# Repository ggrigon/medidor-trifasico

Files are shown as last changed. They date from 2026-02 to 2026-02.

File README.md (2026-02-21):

# Medidor de Tensão Trifásico - ESP32 + PZEM-004T

Medidor trifásico DIY para monitoramento de sistema 220/380V em tempo real. Lê tensão, corrente, potência, energia, frequência e fator de potência das 3 fases com interface web, display OLED, histórico em SD card e integração MQTT.

**Custo estimado:** ~R$ 350-430 (vs R$ 900+ de soluções comerciais como Shelly Pro 3EM)

**Landing page:** [ggrigon.github.io/medidor-trifasico](https://ggrigon.github.io/medidor-trifasico/)

## Funcionalidades

- **Leitura das 3 fases:** tensão, corrente, potência, energia, frequência, fator de potência
- **Display OLED:** 5 páginas auto-rotativas (overview + detalhe de cada fase + alarmes)
- **Dashboard Web:** interface responsiva com gráficos em tempo real via WebSocket
- **Histórico SD Card:** log CSV diário (~1.5 MB/dia), cartão de 32GB = ~58 anos
- **MQTT:** integração com Home Assistant, Grafana (via Telegraf + InfluxDB)
- **Alarmes:** sobretensão (>253V) e subtensão (<197V) com buzzer, LED e notificação web
- **OTA:** atualização de firmware via Wi-Fi

## Lista de Materiais

| # | Componente | Qtd | Função |
|---|---|---|---|
| 1 | ESP32 DevKit V1 (30 pinos, CP2102) | 1 | Microcontrolador principal - WiFi + Bluetooth |
| 2 | PZEM-004T v3.0 com TC split-core 100A | 3 | Medidor de energia por fase (Modbus RTU) |
| 3 | Display OLED SSD1306 128x64 I2C | 1 | Display local para leituras |
| 4 | Módulo SD Card SPI | 1 | Armazenamento de histórico CSV |
| 5 | Cartão microSD (4GB+ classe 10) | 1 | Mídia de armazenamento |
| 6 | Buzzer passivo 5V (BP18) | 1 | Alarme sonoro |
| 7 | Placa perfurada dupla face | 1 | Montagem dos componentes |
| 8 | Fios jumper Dupont (M-M, M-F) | ~40 | Conexões entre componentes |
| 9 | Resistor 4.7k 1/4W | 2 | Pull-up I2C (SDA/SCL) |
| 10 | Resistor 330R 1/4W | 1 | Limitador LED status |
| 11 | Capacitor eletrolítico 100uF 16V | 1 | Desacoplamento 5V |
| 12 | Capacitor cerâmico 100nF 50V | 1 | Filtro 3.3V |
| 13 | LED verde 3mm | 1 | Indicador de status |
| 14 | Borne KRE 2 vias | 1-6 | Conexões parafusadas |
| 15 | Barras de pinos macho/fêmea | 3 | Soquetes e conectores |
| 16 | Fonte 5V 1A (USB ou HLK-PM01) | 1 | Alimentação do ESP32 |

> **IMPORTANTE:** Os PZEMs devem ter CT tipo **split-core** (aberto, tipo grampo). NÃO comprar com CT fechado (closed loop). Ver detalhes completos em [`LISTA_MATERIAIS.md`](LISTA_MATERIAIS.md).

## Pinagem

```
ESP32 GPIO16 (RX2) ──bus──> 3x PZEM TX   (Modbus RTU, addr 0x01/0x02/0x03)
ESP32 GPIO17 (TX2) ──bus──> 3x PZEM RX
ESP32 GPIO21 (SDA) ──────> OLED SDA      (pull-up 4.7k para 3.3V)
ESP32 GPIO22 (SCL) ──────> OLED SCL      (pull-up 4.7k para 3.3V)
ESP32 GPIO23 (MOSI) ─────> SD MOSI
ESP32 GPIO19 (MISO) ─────> SD MISO
ESP32 GPIO18 (SCK) ──────> SD SCK
ESP32 GPIO5  (CS) ───────> SD CS
ESP32 GPIO4  ────────────> Buzzer passivo
ESP32 GPIO2  ── R 330R ──> LED verde
```

Ver esquemático completo em [`hardware/schematic.pdf`](hardware/schematic.pdf) ou [`hardware/schematic.txt`](hardware/schematic.txt).

## Estrutura do Projeto

```
medidor-trifasico/
├── platformio.ini              # Configuração PlatformIO
├── partitions.csv              # Tabela de partições customizada (1.87MB app + 2.06MB LittleFS)
├── LISTA_MATERIAIS.md          # Lista detalhada com preços e links de compra (BR)
├── STATUS.md                   # Andamento do projeto
├── src/
│   ├── main.cpp                # Setup/loop, orquestração cooperativa com millis()
│   ├── config.h                # Pinos, constantes, structs (PhaseData, MeterData)
│   ├── pzem_reader.h/.cpp      # Leitura dos 3 PZEMs via Modbus RTU
│   ├── display_manager.h/.cpp  # OLED SSD1306 (5 páginas rotativas)
│   ├── web_server.h/.cpp       # AsyncWebServer + WebSocket (tempo real)
│   ├── mqtt_client.h/.cpp      # Publicação MQTT (Home Assistant / Grafana)
│   ├── sd_logger.h/.cpp        # Log CSV no SD card (rotação diária)
│   ├── alarm_manager.h/.cpp    # Alarmes sub/sobretensão com buzzer
│   ├── wifi_manager.h/.cpp     # WiFi STA + fallback AP
│   ├── ntp_time.h/.cpp         # Sincronização NTP
│   └── ota_manager.h/.cpp      # Atualização OTA via Wi-Fi
├── data/                        # LittleFS -> dashboard web
│   ├── index.html
│   ├── style.css
│   ├── app.js
│   └── chart.min.js.gz
├── hardware/                    # Projeto PCB KiCad 7 (90x80mm, 2 camadas)
│   ├── medidor-trifasico.kicad_pro
│   ├── medidor-trifasico.kicad_sch
│   ├── medidor-trifasico.kicad_pcb
│   ├── schematic.pdf
│   └── schematic.txt
└── tools/
    └── set_pzem_addresses.cpp   # Utilitário config endereços PZEM
```

## Instalação

### Pré-requisitos
- [PlatformIO CLI](https://platformio.org/install/cli) ou PlatformIO IDE (VS Code)
- Cabo USB-C para o ESP32

### 1. Configurar endereços dos PZEMs

Cada PZEM precisa de um endereço Modbus único. De fábrica, todos vêm com 0xF8. Configure um por vez:

```bash
# Conecte apenas 1 PZEM ao ESP32
# Edite tools/set_pzem_addresses.cpp -> TARGET_ADDRESS = 0x01 (L1)
pio run -e set_pzem_addr -t upload
pio device monitor
# Repita para 0x02 (L2) e 0x03 (L3)
```

### 2. Configurar WiFi e MQTT

Edite `src/config.h`:
```cpp
#define WIFI_SSID       "SuaRedeWiFi"
#define WIFI_PASSWORD   "SuaSenha"
#define MQTT_SERVER     "192.168.1.100"
```

### 3. Compilar e fazer upload

```bash
# Firmware
pio run -e esp32 -t upload

# Filesystem (dashboard web)
pio run -e esp32 -t uploadfs
```

### 4. Verificar

```bash
# Monitor serial
pio device monitor

# Acesse o dashboard web pelo IP mostrado no OLED/serial
```

## Dashboard Web

Acesse `http://IP_DO_ESP32` no navegador. O dashboard mostra:
- 3 cards com leituras de cada fase em tempo real
- Gráfico de potência dos últimos 5 minutos
- Barra de alarme quando há sub/sobretensão

## Integração MQTT

Topics publicados:
```
medidor/L1/voltage    medidor/L2/voltage    medidor/L3/voltage
medidor/L1/current    medidor/L2/current    medidor/L3/current
medidor/L1/power      medidor/L2/power      medidor/L3/power
medidor/L1/energy     medidor/L2/energy     medidor/L3/energy
medidor/L1/frequency  medidor/L2/frequency  medidor/L3/frequency
medidor/L1/pf         medidor/L2/pf         medidor/L3/pf
medidor/data          (JSON completo)
medidor/status        (online/offline - LWT)
medidor/alarm         (alertas com retain)
```

## PCB Customizada (opcional)

Projeto KiCad 7 pronto em `hardware/` para fabricação na JLCPCB:
- PCB carrier board 90x80mm, 2 camadas
- Todos os módulos encaixam via pin header (ESP32, PZEMs, OLED, SD, buzzer)
- Resistores e capacitores em SMD 0805
- Plano de terra em ambas as camadas
- Furos de montagem M3 nos 4 cantos

## Segurança

Os módulos PZEM-004T conectam-se a tensão de rede (220/380V). A instalação **deve ser feita por alguém confortável com eletricidade de rede**, dentro de um gabinete apropriado com espaçamento adequado. Sempre desligue a energia antes de fazer conexões. Os CTs split-core podem ser instalados com a rede energizada, mas tome cuidado com os fios de tensão do PZEM.

## Licença

Este projeto é de uso pessoal/hobby. Use por sua conta e risco.

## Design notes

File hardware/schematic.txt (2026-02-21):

================================================================================
         MEDIDOR TRIFÁSICO v1.0 - Diagrama Esquemático
         PCB Carrier Board para ESP32 + 3x PZEM-004T
================================================================================

                          J4 OLED (1x4)
                     [VCC] [GND] [SDA] [SCL]
                       |     |     |     |
                      3V3   GND    |     |
                                   |     |
                          R1 4.7k  |  R2 4.7k
                          ┌─┤├─┐   |  ┌─┤├─┐
                          │     │   |  │     │
                         3V3    │   | 3V3    │
                                │   |        │
                     ┌──────────┘   |        │
                     │              |        │
  J1 PZEM-L1        │   ┌──────────┘        │
  ┌────────┐         │   │                   │
  │ 5V  ───┼── 5V    │   │                   │
  │ GND ───┼── GND   │   │                   │
  │ TX  ───┼── ┐     │   │                   │
  │ RX  ───┼─┐ │     │   │                   │               J5 SD Card (1x6)
  └────────┘ │ │     │   │                   │               ┌──────────┐
             │ │     │   │                   │          3V3──┼─ 3V3     │
  J2 PZEM-L2 │ │     │   │                   │               │          │
  ┌────────┐ │ │     │   │  ┌──────────────────────────────┐ │          │
  │ 5V  ───┼── 5V   │ │     │   │  │                              │ │          │
  │ GND ───┼── GND  │ │     │   │  │  ESP32 DevKit V1 (U1)        │ │          │
  │ TX  ───┼── ┤    │ │     │   │  │  ┌─────────────────────┐     │ │          │
  │ RX  ───┼─┤ │    │ │     │   │  │  │ 3V3          VIN    │──5V │ │          │
  └────────┘ │ │    │ │     │   │  │  │ EN           GND    │──GND│ │          │
             │ │    │ │     │   │  │  │ VP(36)       D15    │     │ │          │
  J3 PZEM-L3 │ │    │ │     │   │  │  │ VN(39)       D2    │──┐  │ │          │
  ┌────────┐ │ │    │ │     │   │  │  │ D34          D4    │──┼──┼─┼── BZ1+   │
  │ 5V  ───┼── 5V  │ │     │   │  │  │ D35    GPIO16(RX2) │──┼──┼─┼──────────┤── TX
  │ GND ───┼── GND │ │     │   │  │  │ D32    GPIO17(TX2) │──┼──┼─┼──────────┤── RX  (Bus)
  │ TX  ───┼──┘│   │ │     │   │  │  │ D33          D5    │──┼──┼─┼─ CS      │
  │ RX  ───┼──┘    │ │     │   │  │  │ D25          D18   │──┼──┼─┼─ SCK     │
  └────────┘       │ │     │   │  │  │ D26          D19   │──┼──┼─┼─ MISO    │
                   │ │     │   │  │  │ D27    GPIO21(SDA) │──┘  │ │          │
   UART Bus:       │ │     │   │  │  │ D14          RX0   │     │ │          │
   ─────────       │ │     │   │  │  │ D12          TX0   │     │ │          │
   GPIO16(RX2) ────┘ │     │   │  │  │ GND    GPIO22(SCL) │─────┘ │          │
   GPIO17(TX2) ───────┘     │   │  │  │ D13   GPIO23(MOSI)│───────┼─ MOSI    │
                            │   │  │  └─────────────────────┘       │          │
                            │   │  │                               │ GND──GND │
                            │   │  │                               └──────────┘
                            │   │  │
                            │   │  │   LED Status:
                            │   │  │   GPIO2 ── R3(330Ω) ── D1(LED verde) ── GND
                            │   │  │
                            │   │  │   Buzzer:
                            │   │  │   GPIO4 ── BZ1+ ── BZ1- ── GND
                            │   │  │
                            │   │  │
  ALIMENTAÇÃO               │   │  │
  ═══════════               │   │  │
                            │   │  │
  J6 Borne 5V (KF301)      │   │  │
  ┌──────────┐              │   │  │
  │ +5V ─────┼──────────────┼───┼──┼── 5V Rail ── ESP32 VIN, J1-J3 5V
  │ GND ─────┼──────────────┼───┼──┼── GND Rail
  └──────────┘              │   │  │
       │                    │   │  │
      ═╪═ C1 100µF         │   │  │
       │  (5V ↔ GND)       │   │  │
      GND                  │   │  │
                            │   │  │
  ESP32 3V3 pin ────────────┼───┼──┼── 3V3 Rail ── J4 VCC, J5 3V3, R1, R2
       │                    │   │  │
      ═╪═ C2 100nF         │   │  │
       │  (3V3 ↔ GND)      │   │  │
      GND                  │   │  │

================================================================================
  TABELA DE CONEXÕES (conforme config.h)
================================================================================

  Função          │ GPIO ESP32  │ Destino              │ Notas
  ────────────────┼─────────────┼──────────────────────┼─────────────────────
  PZEM RX (recv)  │ GPIO16      │ J1.TX, J2.TX, J3.TX  │ Barramento paralelo
  PZEM TX (send)  │ GPIO17      │ J1.RX, J2.RX, J3.RX  │ Barramento paralelo
  OLED SDA        │ GPIO21      │ J4.SDA               │ Pull-up 4.7k → 3V3
  OLED SCL        │ GPIO22      │ J4.SCL               │ Pull-up 4.7k → 3V3
  SD MOSI         │ GPIO23      │ J5.MOSI              │ SPI padrão
  SD MISO         │ GPIO19      │ J5.MISO              │ SPI padrão
  SD SCK          │ GPIO18      │ J5.SCK               │ SPI padrão
  SD CS           │ GPIO5       │ J5.CS                │ Chip select
  Buzzer          │ GPIO4       │ BZ1 pin 1            │ Pin 2 → GND
  LED Status      │ GPIO2       │ R3(330Ω) → D1        │ LED verde 3mm

================================================================================
  LAYOUT PCB (90mm x 80mm) - Vista Superior
================================================================================

  ┌──[H1]──────────────── J4 OLED ─────────────────────[H2]──┐
  │           ┌──────────────────────┐                        │
  │           │ VCC  GND  SDA  SCL  │  R1  R2                │
  │           └──────────────────────┘  4k7  4k7              │
  │                                                           │
  │ J1 PZEM-L1    ┌───────────────────────────┐    J5 SD Card │
  │ ┌──────┐      │                           │    ┌──────┐   │
  │ │ 5V   │      │   ┌───────────────────┐   │    │ 3V3  │   │
  │ │ GND  │      │   │                   │   │    │ CS   │   │
  │ │ TX   │      │   │   ESP32 DevKit    │   │    │ MOSI │   │
  │ │ RX   │      │   │      (U1)        │   │    │ SCK  │   │
  │ └──────┘      │   │                   │   │    │ MISO │   │
  │               │   │   30 pinos        │   │    │ GND  │   │
  │ J2 PZEM-L2    │   │   (2x15)         │   │    └──────┘   │
  │ ┌──────┐      │   │                   │   │               │
  │ │ 5V   │      │   │   USB ↓          │   │               │
  │ │ GND  │      │   └───────────────────┘   │     C2        │
  │ │ TX   │      │                           │    100nF      │
  │ │ RX   │      └───────────────────────────┘               │
  │ └──────┘                                        R3  D1    │
  │                                                330Ω LED   │
  │ J3 PZEM-L3                                                │
  │ ┌──────┐                                        BZ1       │
  │ │ 5V   │                                       Buzzer     │
  │ │ GND  │       C1                                         │
  │ │ TX   │      100µF     J6 Borne 5V                       │
  │ │ RX   │               ┌────────────┐                     │
  │ └──────┘               │ +5V    GND │                     │
  │                        └────────────┘                     │
  │                                                           │
  └──[H3]────────────────────────────────────────────[H4]─────┘

  Dimensões: 90mm × 80mm (2 camadas, plano GND ambos lados)
  Furos: M3 nos 4 cantos (3.5mm das bordas)
  Fabricação: JLCPCB (FR-4, 1.6mm, HASL)

================================================================================
  LISTA DE MATERIAIS (BOM)
================================================================================

  Ref  │ Componente              │ Valor    │ Footprint            │ Qtd
  ─────┼─────────────────────────┼──────────┼──────────────────────┼────
  U1   │ ESP32 DevKit V1         │ -        │ 2x PinHeader 1x15   │  1
  J1-3 │ Conector PZEM           │ -        │ PinHeader 1x4        │  3
  J4   │ Conector OLED           │ -        │ PinHeader 1x4        │  1
  J5   │ Conector SD Card        │ -        │ PinHeader 1x6        │  1
  J6   │ Borne parafuso          │ -        │ KF301 5mm 2P         │  1
  BZ1  │ Conector Buzzer         │ -        │ PinHeader 1x2        │  1
  R1   │ Resistor pull-up SDA    │ 4.7kΩ   │ 0805 SMD             │  1
  R2   │ Resistor pull-up SCL    │ 4.7kΩ   │ 0805 SMD             │  1
  R3   │ Resistor LED            │ 330Ω    │ 0805 SMD             │  1
  C1   │ Capacitor desacoplamento│ 100µF   │ Eletrolítico radial  │  1
  C2   │ Capacitor filtro        │ 100nF   │ 0805 SMD             │  1
  D1   │ LED status              │ Verde   │ 3mm THT              │  1
  H1-4 │ Furo de montagem        │ M3      │ 3.2mm                │  4

================================================================================

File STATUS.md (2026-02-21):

# Status do Projeto - Medidor Trifásico ESP32

> Atualizado em: 21/02/2026

## Resumo

Medidor trifásico DIY com ESP32 + 3x PZEM-004T para monitoramento de sistema 220/380V em tempo real. Dashboard web, display OLED, log em SD card e integração MQTT.

---

## Firmware

| Módulo | Arquivo | Status |
|---|---|---|
| Configuração e pinos | `src/config.h` | Pronto |
| Loop principal | `src/main.cpp` | Pronto |
| Leitura PZEM (3 fases) | `src/pzem_reader.cpp/.h` | Pronto |
| Display OLED SSD1306 | `src/display_manager.cpp/.h` | Pronto |
| Web Server + WebSocket | `src/web_server.cpp/.h` | Pronto |
| Cliente MQTT | `src/mqtt_client.cpp/.h` | Pronto |
| Log CSV no SD Card | `src/sd_logger.cpp/.h` | Pronto |
| Alarmes sub/sobretensão | `src/alarm_manager.cpp/.h` | Pronto |
| WiFi STA + fallback AP | `src/wifi_manager.cpp/.h` | Pronto |
| Sincronização NTP | `src/ntp_time.cpp/.h` | Pronto |
| OTA (over-the-air) | `src/ota_manager.cpp/.h` | Pronto |
| Dashboard web (HTML/CSS/JS) | `data/` | Pronto |
| Utilitário endereçamento PZEM | `tools/set_pzem_addresses.cpp` | Pronto |

**Compilação:** OK - RAM 14.4%, Flash 49.3% (bastante folga)

**Ambientes PlatformIO:**
- `esp32` - firmware principal
- `set_pzem_addr` - utilitário de configuração Modbus

---

## Hardware

### Projeto PCB (KiCad 7)

| Arquivo | Descrição | Status |
|---|---|---|
| `hardware/medidor-trifasico.kicad_pro` | Projeto KiCad | Pronto |
| `hardware/medidor-trifasico.kicad_sch` | Esquemático | Pronto |
| `hardware/medidor-trifasico.kicad_pcb` | Layout PCB 90x80mm 2 camadas | Pronto |
| `hardware/schematic.pdf` | PDF do esquemático | Pronto |
| `hardware/schematic.txt` | Diagrama ASCII de referência | Pronto |

> PCB pronta para fabricar na JLCPCB quando migrar da placa perfurada.

### Esquema de Conexões

```
ESP32 GPIO16 (RX2) ──bus──> 3x PZEM TX  (Modbus RTU, addr 0x01/0x02/0x03)
ESP32 GPIO17 (TX2) ──bus──> 3x PZEM RX
ESP32 GPIO21 (SDA) ──────> OLED SDA     (pull-up 4.7k)
ESP32 GPIO22 (SCL) ──────> OLED SCL     (pull-up 4.7k)
ESP32 GPIO23 (MOSI) ─────> SD MOSI
ESP32 GPIO19 (MISO) ─────> SD MISO
ESP32 GPIO18 (SCK) ──────> SD SCK
ESP32 GPIO5  (CS) ───────> SD CS
ESP32 GPIO4  ────────────> Buzzer passivo
ESP32 GPIO2  ── R 330R ──> LED verde
```

---

## Compras

### Usinainfo (local, buscar na loja - sem frete)

| Cód | Item | Preço PIX | Status |
|-----|---|---|---|
| 08240 | ESP32 NodeMCU 30 Pinos CP2102 | R$ 66,36 | No carrinho |
| 10204 | Expansor ESP32 DevKit V1 30 Pinos | R$ 23,56 | No carrinho |
| 08483 | Display OLED 0.96" I2C 128x64 Branco | R$ 25,46 | No carrinho |
| 05887 | SD Card para Arduino / Leitor Micro SD | R$ 7,89 | No carrinho |
| 06403 | Placa Ilhada 432 Furos Dupla Face 5x7cm | R$ 4,99 | No carrinho |
| 06820 | Placa Ilhada 1260 Furos Dupla Face 8x12cm | R$ 8,31 | No carrinho |
| 06017 | Barra Pinos Macho 1x40 2.54mm | R$ 1,89 | No carrinho |
| 07279 | Barra Pinos Fêmea 20p 2.54mm (x2) | R$ 4,54 | No carrinho |
| 05861 | Jumper Premium M-M 20cm x20 | R$ 5,89 | No carrinho |
| 05632 | Jumper Premium M-F 20cm x20 | R$ 5,51 | No carrinho |
| 06354 | Borne KRE 12mm 2 Vias (x11) | R$ 20,69 | No carrinho |
| 07085 | Resistor 4.7k 1/4W kit 10un | R$ 1,62 | No carrinho |
| 06254 | Resistor 330R 1/4W kit 10un | R$ 2,00 | No carrinho |
| 06330 | Capacitor Eletrolítico 100uF 16V kit 10un | R$ 3,33 | No carrinho |
| 07323 | LED Verde 3mm Difuso kit 10un | R$ 3,40 | No carrinho |
| 07328 | LED Amarelo 3mm Difuso kit 10un | R$ 3,03 | No carrinho |
| 06638 | LED Vermelho 3mm Difuso kit 10un | R$ 4,01 | No carrinho |
| 07768 | Buzzer Passivo BP18 GND Low | R$ 6,94 | No carrinho |
| | **Total Usinainfo (29 itens, boleto)** | **R$ 199,40** | Pronto para comprar |

### Mercado Livre

| Item | Preço | Status |
|---|---|---|
| Capacitor Cerâmico 100nF 50V x100 pcs | ~R$ 15-20 | Comprado - chega quarta |

### AliExpress

| Item | Preço | Status |
|---|---|---|
| 3x PZEM-004T v3.0 com CT **split-core** 100A | ~R$ 96-168 | Comprado - 30-60 dias |

### Já tem

| Item |
|------|
| Cartão micro SD (4GB+ classe 10) |

### Custo total estimado: **R$ 310-390**

---

## Próximos Passos

### Fase 1 - Montagem imediata (quando buscar na Usinainfo)
- [ ] Soldar barras de pinos fêmea na placa perfurada (soquete ESP32)
- [ ] Montar ESP32 + OLED + SD Card + Buzzer + LED na placa
- [ ] Conectar conforme esquema de pinos
- [ ] Fazer upload do firmware (`pio run -e esp32 -t upload`)
- [ ] Fazer upload do dashboard (`pio run -e esp32 -t uploadfs`)
- [ ] Testar Wi-Fi, dashboard web, display OLED, log SD, buzzer

### Fase 2 - Integração PZEM (quando chegar do AliExpress)
- [ ] Configurar endereços Modbus (0x01, 0x02, 0x03) um por vez
- [ ] Conectar os 3 PZEMs no barramento UART (GPIO 16/17)
- [ ] Testar leitura das 3 fases
- [ ] Instalar na caixa com prensa-cabos
- [ ] Abraçar os cabos das fases com os CTs split-core

### Fase 3 - Monitoramento e ajustes
- [ ] Configurar MQTT (Home Assistant / Grafana)
- [ ] Verificar precisão das leituras vs multímetro
- [ ] Ajustar limiares de alarme se necessário
- [ ] Monitorar estabilidade por alguns dias

### Fase 4 - Melhorias futuras (opcional)
- [ ] Migrar para PCB customizada (arquivos KiCad prontos em `hardware/`)
- [ ] Implementar OTA para atualizações sem fio
- [ ] Adicionar medição do neutro (4º PZEM)
- [ ] Implementar exportação de dados (download CSV pelo dashboard)
- [ ] Notificações push (Telegram/WhatsApp)

---

## Limitações Conhecidas

- PZEM-004T não mede potência bidirecional (sempre positiva) - não distingue consumo vs injeção solar
- WiFi/MQTT credentials hardcoded em `config.h` (sem portal de configuração)
- CT split-core 100A com abertura de ~16mm (cabe cabo até 10mm²)
- Precisão do PZEM: classe 1% para tensão, classe 2% para corrente

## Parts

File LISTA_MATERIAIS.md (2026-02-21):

# Lista de Materiais - Medidor Trifásico ESP32

## Componentes Principais

| # | Componente | Qtd | Especificação | Preço PIX (R$) | Onde comprar |
|---|---|---|---|---|---|
| 1 | **ESP32 DevKit V1** | 1 | 30 pinos, CP2102, USB-C, 4MB flash | R$ 66,36 | [Usinainfo](https://www.usinainfo.com.br/nodemcu/esp32-nodemcu-iot-com-wifi-e-bluetooth-30-pinos-com-cp2102-5147.html) |
| 2 | **PZEM-004T v3.0** com TC **split-core** 100A | 3 | Modbus RTU, medidor AC, **CT aberto obrigatório** | R$ 55-80/un | [Mercado Livre](https://lista.mercadolivre.com.br/pzem-004) ou [AliExpress](https://www.aliexpress.com/item/32907139707.html) |
| 3 | **Display OLED SSD1306** | 1 | 0.96", 128x64, I2C (4 pinos), branco | R$ 25,46 | [Usinainfo](https://www.usinainfo.com.br/display-arduino/display-oled-096-i2c-128x64-branco-para-arduino-5366.html) |
| 4 | **Módulo SD Card** | 1 | SPI, slot micro SD, 3.3V/5V | R$ 7,89 | [Usinainfo](https://www.usinainfo.com.br/outros-modulos-arduino/sd-card-para-arduino-leitor-micro-sd-card-2637.html) |
| 5 | **Cartão micro SD** | 1 | 4GB+ classe 10 (SanDisk/Kingston) | R$ 20-30 | Qualquer papelaria ou [Mercado Livre](https://lista.mercadolivre.com.br/cartao-micro-sd-16gb-classe-10) |
| 6 | **Buzzer passivo BP18** | 1 | 5V, acionamento GND Low | R$ 6,94 | [Usinainfo](https://www.usinainfo.com.br/buzzer-arduino/buzzer-passivo-modulo-transdutor-bp18-acionamento-gnd-low-4708.html) |

> **IMPORTANTE sobre PZEM-004T:** Exigir CT **split-core (aberto)** que abre como grampo para abraçar o cabo sem desconectar. NÃO comprar com CT fechado (closed loop). Na Usinainfo tem o V4.0 a R$78,38 mas vem com CT fechado. Preferir Mercado Livre ou AliExpress com split-core.

## Alimentação

| # | Componente | Qtd | Especificação | Preço PIX (R$) | Onde comprar |
|---|---|---|---|---|---|
| 7 | **Fonte HLK-PM01** (opção A) | 1 | AC 220V -> DC 5V 600mA, embutida | R$ 18-35 | [ML](https://lista.mercadolivre.com.br/hlk-pm01-5v) ou [AliExpress](https://www.aliexpress.com/wholesale?SearchText=HLK-PM01+AC-DC+5V+600mA) |
| 8 | **Carregador USB 5V** (opção B) | 1 | Qualquer carregador de celular + cabo USB | R$ 0 (reaproveitar) | - |

## Montagem em Placa Perfurada

| # | Componente | Qtd | Especificação | Preço PIX (R$) | Onde comprar |
|---|---|---|---|---|---|
| 9 | **Placa perfurada dupla face 5x7cm** | 1 | 432 furos, passo 2.54mm, fibra de vidro | R$ 4,99 | [Usinainfo #06403](https://www.usinainfo.com.br/placa-de-fibra-de-vidro/placa-de-circuito-impresso-ilhada-universal-432-furos-dupla-face-5x7cm-3126.html) |
| 9b | **Placa perfurada dupla face 8x12cm** (alternativa maior) | 1 | 1260 furos, passo 2.54mm, fibra de vidro | R$ 8,31 | [Usinainfo #06820](https://www.usinainfo.com.br/placa-de-fibra-de-vidro/placa-de-circuito-impresso-ilhada-1260-furos-dupla-face-8x12cm-3521.html) |
| 10 | **Barra de pinos fêmea 20p** | 2 | 2.54mm, empilhável (soquete ESP32 - cortar 2x15) | R$ 2,27/un | [Usinainfo #07279](https://www.usinainfo.com.br/barras-de-pinos/barra-de-20-pinos-254mm-femea-conector-empilhavel-para-pci-3964.html) |
| 11 | **Barra de pinos macho 1x40** | 1 | 2.54mm, 180 graus (cortar no tamanho) | R$ 1,89 | [Usinainfo #06017](https://www.usinainfo.com.br/barras-de-pinos/barra-de-pinos-macho-1x40-vias-com-passo-de-254mm-180-preto-2748.html) |
| 12 | **Jumper M-M 20cm** kit 20pcs | 1 | Dupont Premium, 24 AWG, 10 cores | R$ 5,89 | [Usinainfo #05861](https://www.usinainfo.com.br/jumper/jumper-premium-para-protoboard-macho-macho-20cm-kit-c-20-pecas-2611.html) |
| 12b | **Jumper M-F 20cm** kit 20pcs | 1 | Dupont Premium, 24 AWG, 10 cores | R$ 5,51 | [Usinainfo #05632](https://www.usinainfo.com.br/jumper/jumper-premium-para-protoboard-macho-femea-20cm-kit-c-20-pecas-2314.html) |
| 13 | **Borne KRE 2 vias** | 1-6 | 12mm, passo 5.08mm, max 10A | R$ 1,88/un | [Usinainfo](https://www.usinainfo.com.br/borne-kre-e-xt60/conector-borne-kre-12mm-2-vias-azul-3077.html) |

## Componentes Passivos

| # | Componente | Qtd | Especificação | Preço PIX (R$) | Onde comprar |
|---|---|---|---|---|---|
| 14 | **Resistor 4.7k** kit 10un | 1 kit | 1/4W THT, CR25, +/-5% - pull-up I2C | R$ 1,62 | [Usinainfo #07085](https://www.usinainfo.com.br/resistor-14-watt/resistor-4k7-14w-kit-com-10-unidades-3773.html) |
| 15 | **Resistor 330R** kit 10un | 1 kit | 1/4W THT, CR25, +/-5% - limitador LED | R$ 2,00 | [Usinainfo #06254](https://www.usinainfo.com.br/resistor-14-watt/resistor-330r-14w-kit-com-10-unidades-2977.html) |
| 16 | **Capacitor eletrolítico 100uF 16V** kit 10un | 1 kit | Radial, polarizado - desacoplamento 5V | R$ 3,33 | [Usinainfo](https://www.usinainfo.com.br/capacitor-eletrolitico/capacitor-eletrolitico-100uf-16v-kit-com-10-unidades-3053.html) |
| 17 | **Capacitor cerâmico 100nF 50V** | 1 | Código 104 - filtro 3.3V | ~R$ 0,50 | **Indisponível na Usinainfo** - comprar no [ML](https://lista.mercadolivre.com.br/capacitor-ceramico-100nf) ou [AliExpress](https://www.aliexpress.com/wholesale?SearchText=ceramic+capacitor+100nF+104+50V) |
| 18 | **LED verde 3mm difuso** kit 10un | 1 kit | LV3MD, 2~2.2V, 20mA max | R$ 3,40 | [Usinainfo #07323](https://www.usinainfo.com.br/led-difuso/led-verde-3mm-difuso-kit-com-10-unidades-4008.html) |

## Caixa e Acabamento

| # | Componente | Qtd | Especificação | Preço PIX (R$) | Onde comprar |
|---|---|---|---|---|---|
| 19 | **Caixa Patola PB-114** | 1 | 55x97x148mm, com tampa | R$ 31,92 | [Usinainfo](https://www.usinainfo.com.br/caixas-patola/caixa-patola-case-para-montagem-55-x-97-x-148-mm-pb-114-3880.html) |
| 19b | **Caixa Patola PB-112** (alternativa menor) | 1 | 53x85x124mm, com tampa | R$ 24,70 | [Usinainfo](https://www.usinainfo.com.br/caixas-patola/caixa-patola-case-para-montagem-53-x-85-x-124-mm-pb-112-3879.html) |
| 19c | **Case SZOMK Trilho DIN** (alternativa quadro) | 1 | 145x90x40mm, com bornes, trilho DIN | R$ 66,68 | [Usinainfo](https://www.usinainfo.com.br/caixas-patola/case-szomk-para-montagem-145x90x40mm-gabinete-para-trilho-din-bornes-5027.html) |
| 20 | **Prensa-cabo PG7** | 3-4 | IP67, nylon, para cabo 3.5-6.5mm | R$ 2,76/un | [Usinainfo](https://www.usinainfo.com.br/conectores-e-adaptadores/prensa-cabo-pg7-ip67-14-para-condutor-de-35-a-65mm-5043.html) |

## Ferramentas Necessárias (se não tiver)

| Ferramenta | Observação |
|---|---|
| Ferro de solda + estanho | Para montar na placa perfurada |
| Multímetro | Para verificar conexões |
| Chave phillips pequena | Para os bornes |
| Alicate de corte | Para fios |

## Resumo de Custo (R$ PIX - Fev/2026)

### Opção 1: Tudo na Usinainfo (exceto PZEM e cap 100nF)

| # | Item | Preço PIX |
|---|---|---|
| 1 | ESP32 DevKit V1 | R$ 66,36 |
| 2 | Display OLED SSD1306 | R$ 25,46 |
| 3 | Módulo SD Card | R$ 7,89 |
| 4 | Buzzer Passivo BP18 | R$ 6,94 |
| 5 | Placa perfurada 8x12cm dupla face | R$ 8,31 |
| 6 | 2x Barra pinos fêmea 20p | R$ 4,54 |
| 7 | Barra pinos macho 1x40 | R$ 1,89 |
| 8 | Jumper M-M 20cm x20 | R$ 5,89 |
| 9 | Jumper M-F 20cm x20 | R$ 5,51 |
| 10 | 2x Borne KRE 2 vias | R$ 3,76 |
| 11 | Resistor 4.7k kit 10un | R$ 1,62 |
| 12 | Resistor 330R kit 10un | R$ 2,00 |
| 13 | Capacitor 100uF 16V kit 10un | R$ 3,33 |
| 14 | LED verde 3mm kit 10un | R$ 3,40 |
| 15 | Caixa Patola PB-114 | R$ 31,92 |
| 16 | 4x Prensa-cabo PG7 | R$ 11,04 |
| | **Subtotal Usinainfo** | **R$ 189,86** |
| 17 | 3x PZEM-004T split-core (ML) | ~R$ 165-240 |
| 18 | Cartão micro SD 16GB (ML) | ~R$ 20 |
| 19 | Capacitor cerâmico 100nF (ML) | ~R$ 2 |
| | **TOTAL ESTIMADO** | **R$ 377-452** |

### Opção 2: PZEM pelo AliExpress (econômica, demora 30-60 dias)

| Categoria | Custo |
|---|---|
| Usinainfo (buscar, sem frete) | R$ 189,86 |
| 3x PZEM-004T AliExpress | ~R$ 96-168 |
| Cartão SD + cap 100nF (ML) | ~R$ 22 |
| **Total estimado** | **R$ 308-380** |

## Dicas de Compra

### PZEM-004T (item mais crítico)
- **OBRIGATÓRIO**: CT tipo **split-core** (abre como grampo). NÃO comprar CT fechado (closed loop)
- Versão **v3.0 ou v4.0** - ambas usam Modbus RTU e são compatíveis com a biblioteca
- Confirmar que vem com TC de 100A incluso na embalagem
- Comprar 3 unidades do mesmo vendedor para garantir consistência
- Abertura interna do CT120: ~16mm (cabe cabo até 10mm²)
- [AliExpress - Split CT](https://www.aliexpress.com/item/32907139707.html) | [ML - Buscar](https://lista.mercadolivre.com.br/pzem-004)

### ESP32 DevKit V1
- Preferir versão com **30 pinos** (mais compacta). CH340 ou CP2102 tanto faz
- Selecionar variante **USB-C** na página do produto
- [Usinainfo](https://www.usinainfo.com.br/nodemcu/esp32-nodemcu-iot-com-wifi-e-bluetooth-30-pinos-com-cp2102-5147.html)

### Display OLED
- Confirmar que é **I2C** (4 pinos: VCC, GND, SDA, SCL). Existem versões SPI com 7 pinos - NÃO usar essa
- [Usinainfo](https://www.usinainfo.com.br/display-arduino/display-oled-096-i2c-128x64-branco-para-arduino-5366.html)

### Placa Perfurada
- **5x7cm** (R$ 4,99) para montagem compacta ou **8x12cm** (R$ 8,31) se quiser mais espaço
- Preferir **dupla face** (fibra de vidro) - mais resistente que fenolite

### Caixa
- **PB-114** (14.8x9.7x5.5cm, R$31,92) - tamanho ideal para o projeto
- **PB-112** (12.4x8.5x5.3cm, R$24,70) - alternativa menor e mais barata
- **Case SZOMK Trilho DIN** (14.5x9x4cm, R$66,68) - se quiser montar no quadro elétrico

### Capacitor cerâmico 100nF
- Único item **indisponível** na Usinainfo (era outlet com defeito de medição)
- Comprar no Mercado Livre ou em qualquer loja de eletrônica - custa centavos

### HLK-PM01
- Cuidado na instalação - entrada AC direto na rede 220V! Alternativa mais segura: usar carregador USB externo
- [AliExpress](https://www.aliexpress.com/wholesale?SearchText=HLK-PM01+AC-DC+5V+600mA)

## PCB Customizada (opcional, futura)

Arquivos KiCad 7 prontos em `hardware/` para fabricação na JLCPCB quando quiser migrar da placa perfurada:
- `hardware/medidor-trifasico.kicad_pro` - Projeto
- `hardware/medidor-trifasico.kicad_sch` - Esquemático
- `hardware/medidor-trifasico.kicad_pcb` - Layout PCB (90x80mm, 2 camadas)
- `hardware/schematic.pdf` - PDF do esquemático
- `hardware/schematic.txt` - Diagrama ASCII de referência

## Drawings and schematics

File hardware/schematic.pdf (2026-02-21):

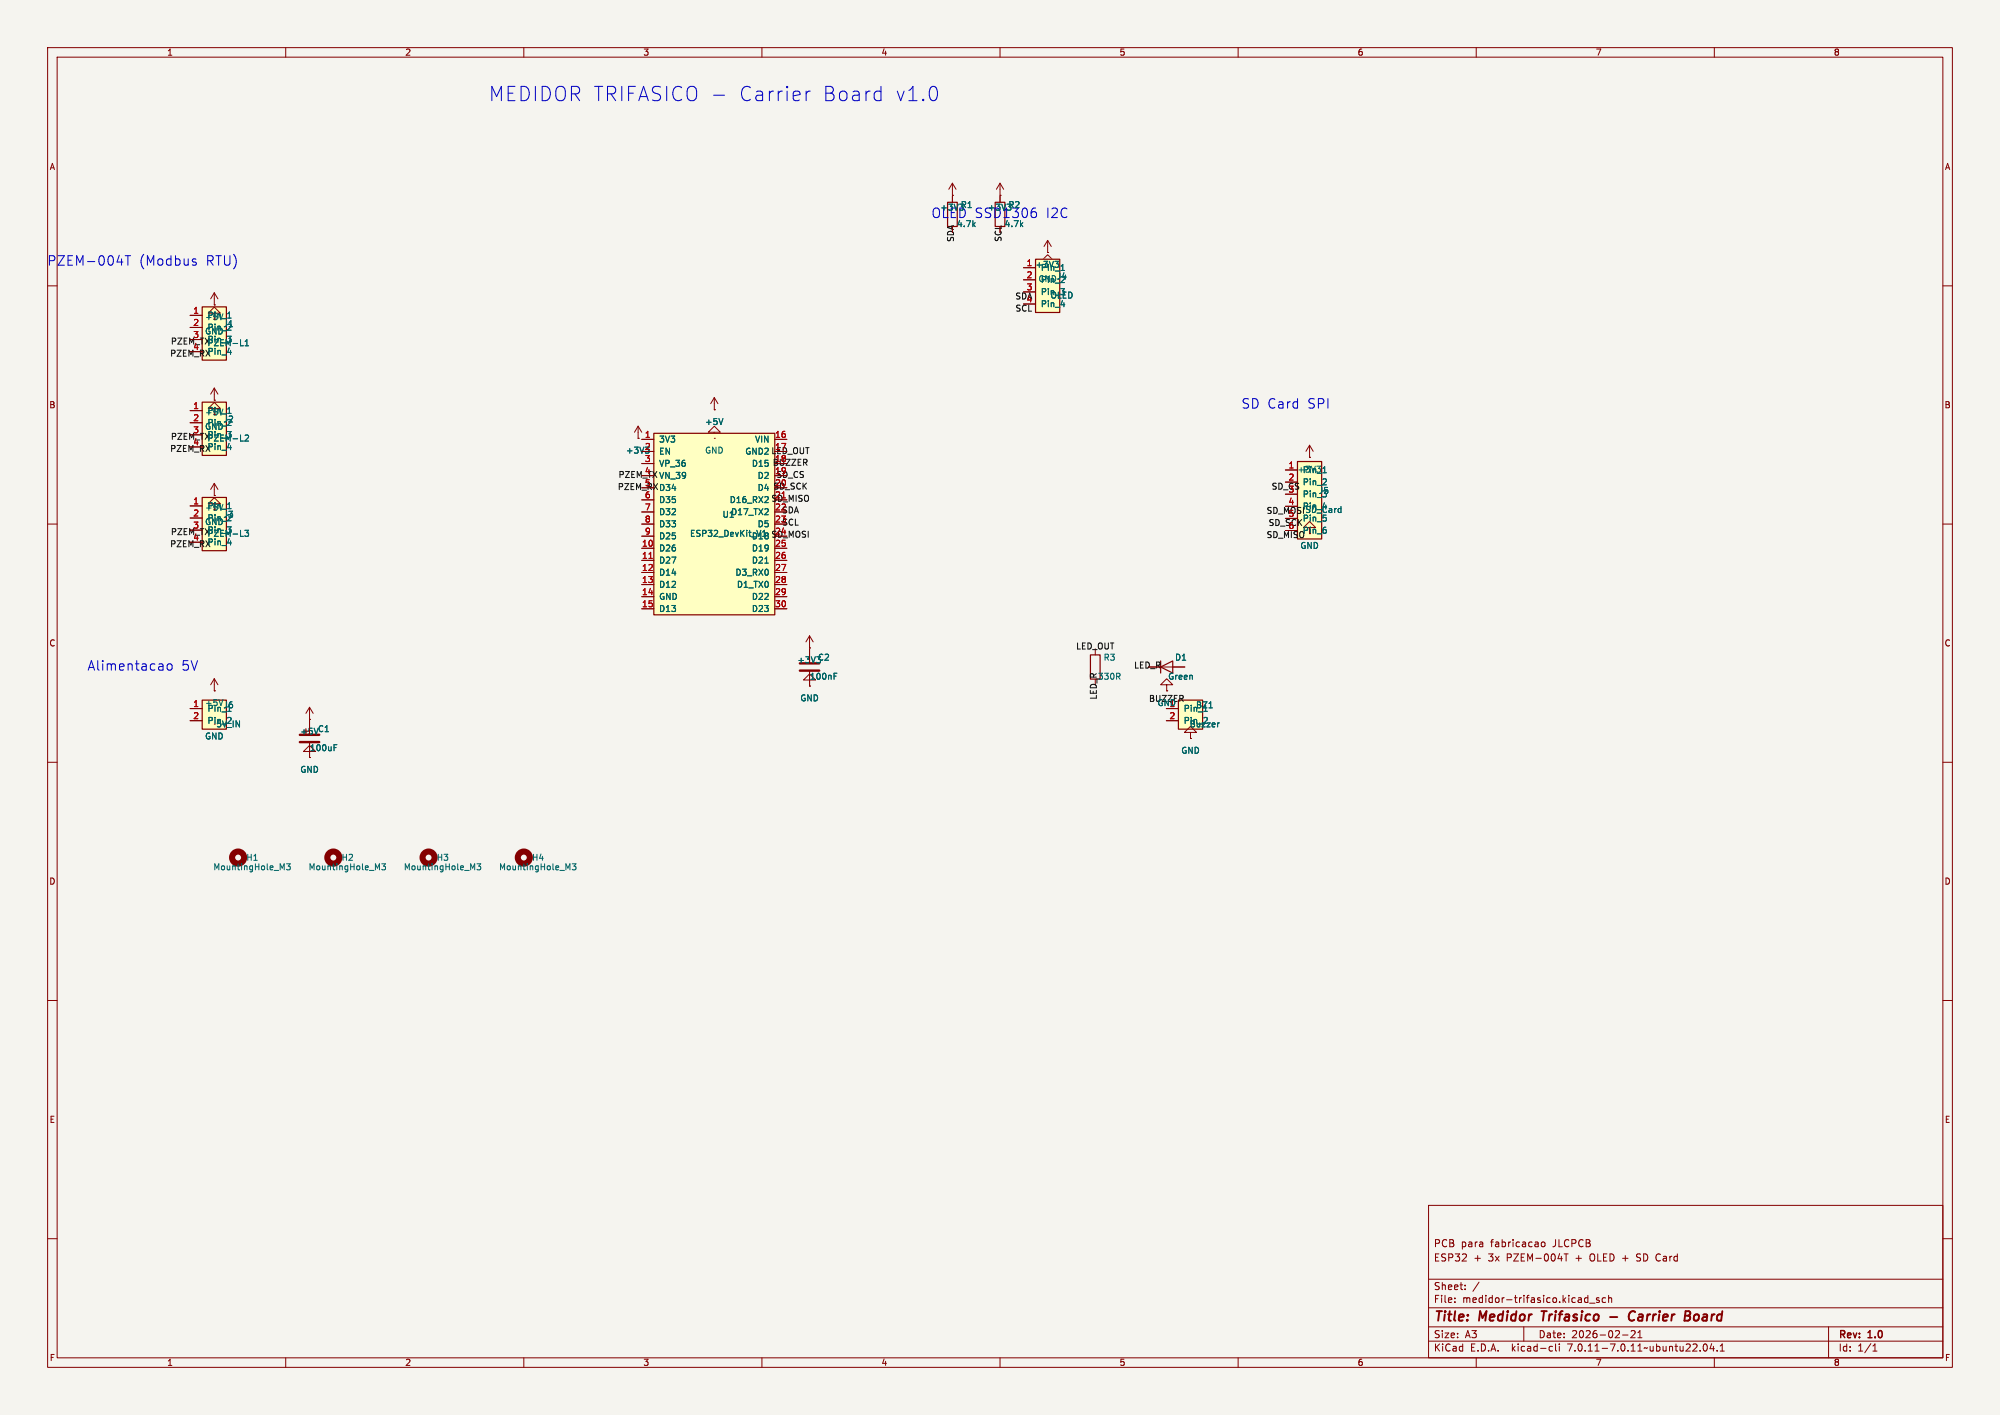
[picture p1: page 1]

MEDIDOR TRIFASICO - Carrier Board v1.0

SCL SDA SCL SCL SD_CS

Id: 1/1 Title: Medidor Trifasico - Carrier Board

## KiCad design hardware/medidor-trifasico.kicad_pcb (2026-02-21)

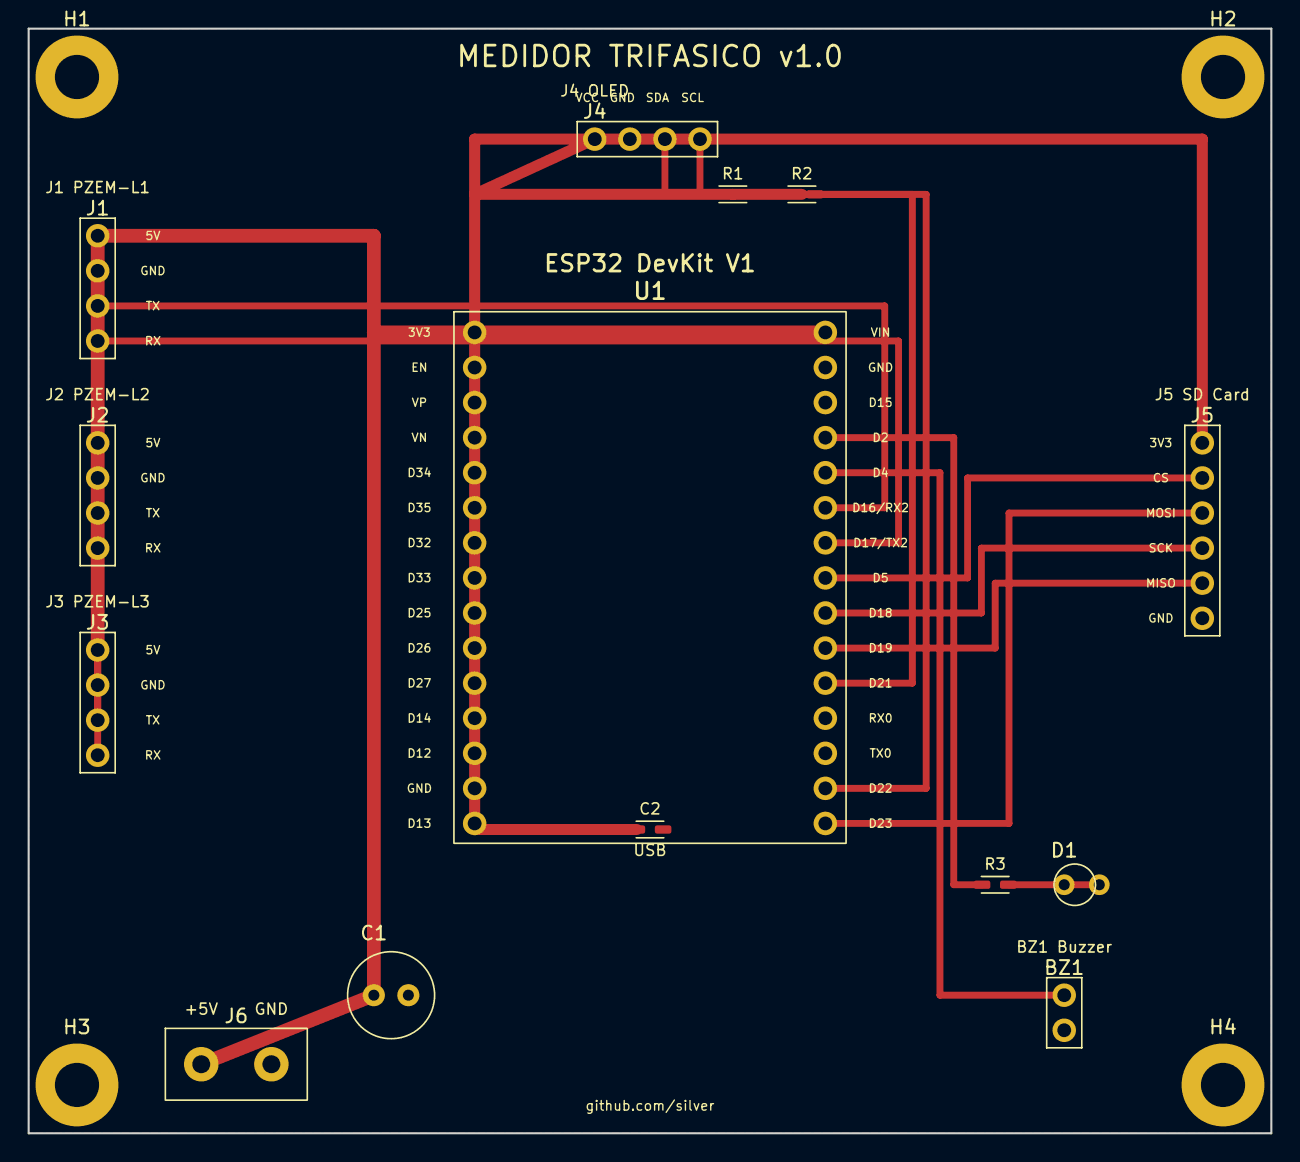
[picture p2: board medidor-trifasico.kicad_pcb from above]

Board: 2 copper layers, 90.0 x 80.0 mm, 18 parts (0 on the bottom side), 14 nets.

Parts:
BZ1: Buzzer; Connector_PinHeader_1x02_P2.54mm_Vertical
C1: 100uF; CP_Radial_D6.3mm_P2.50mm
C2: 100nF; R_0805_2012Metric
D1: LED_Green; LED_D3.0mm
H1, H2, H3, H4: MountingHole_M3; MountingHole_3.2mm_M3
J1: PZEM-L1; Connector_PinHeader_1x04_P2.54mm_Vertical
J2: PZEM-L2; Connector_PinHeader_1x04_P2.54mm_Vertical
J3: PZEM-L3; Connector_PinHeader_1x04_P2.54mm_Vertical
J4: OLED; Connector_PinHeader_1x04_P2.54mm_Vertical
J5: SD_Card; Connector_PinHeader_1x06_P2.54mm_Vertical
J6: 5V_IN; TerminalBlock_bornier-2_P5.08mm
R1, R2: 4.7k; R_0805_2012Metric
R3: 330R; R_0805_2012Metric
U1: ESP32_DevKit_V1

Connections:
+3V3: C2.1, J4.1, J5.1, R1.1, R2.1, U1.1
+5V: C1.1, J1.1, J2.1, J3.1, J6.1, U1.16
BUZZER: BZ1.1, U1.20
GND: BZ1.2, C1.2, C2.2, D1.1, J1.2, J2.2, J3.2, J4.2, J5.6, J6.2, U1.14, U1.17
LED_OUT: R3.1, U1.19
LED_R: D1.2, R3.2
PZEM_RX: J1.4, J2.4, J3.4, U1.22
PZEM_TX: J1.3, J2.3, J3.3, U1.21
SCL: J4.4, R2.2, U1.29
SDA: J4.3, R1.2, U1.26
SD_CS: J5.2, U1.23
SD_MISO: J5.5, U1.25
SD_MOSI: J5.3, U1.30
SD_SCK: J5.4, U1.24

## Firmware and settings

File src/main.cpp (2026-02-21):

#include <Arduino.h>
#include "config.h"
#include "wifi_manager.h"
#include "ntp_time.h"
#include "pzem_reader.h"
#include "display_manager.h"
#include "web_server.h"
#include "sd_logger.h"
#include "mqtt_client.h"
#include "alarm_manager.h"
#include "ota_manager.h"

// --- Instancias dos modulos ---
WiFiManager   wifiMgr;
NTPTime       ntpTime;
PZEMReader    pzemReader;
DisplayManager displayMgr;
WebServerManager webServer;
SDLogger      sdLogger;
MQTTClient    mqttClient;
AlarmManager  alarmMgr;
OTAManager    otaMgr;

// --- Dados compartilhados ---
MeterData meterData;

// --- Timers (millis) ---
unsigned long lastPZEM      = 0;
unsigned long lastDisplay   = 0;
unsigned long lastWebSocket = 0;
unsigned long lastSDLog     = 0;
unsigned long lastMQTT      = 0;
unsigned long lastAlarm     = 0;
unsigned long lastWiFiCheck = 0;
unsigned long lastNTPSync   = 0;

// --- Callback de alarme ---
void onAlarm(int phase, const String& type, float voltage) {
    String msg = "L" + String(phase + 1) + " " + type + " " + String(voltage, 1) + "V";
    webServer.sendAlarm(msg);
    mqttClient.publishAlarm(phase, type, voltage);
}

void setup() {
    Serial.begin(115200);
    delay(500);
    Serial.println("\n============================");
    Serial.println(" Medidor Trifasico ESP32");
    Serial.println("============================\n");

    // 1. Display (mostra mensagens de status durante init)
    displayMgr.begin();
    displayMgr.showMessage("Conectando WiFi...");

    // 2. WiFi
    wifiMgr.begin();
    displayMgr.showMessage("WiFi: " + wifiMgr.getIP());

    // 3. NTP
    ntpTime.begin();
    ntpTime.sync();

    // 4. PZEM
    displayMgr.showMessage("Init PZEMs...");
    pzemReader.begin();

    // 5. Web Server + OTA
    webServer.begin();
    otaMgr.begin();
    otaMgr.setupWebOTA(webServer.getServer());

    // 6. SD Card
    displayMgr.showMessage("Init SD Card...");
    sdLogger.begin();

    // 7. MQTT
    mqttClient.begin();

    // 8. Alarmes
    alarmMgr.begin();
    alarmMgr.onAlarm(onAlarm);

    Serial.println("\n[MAIN] Todos os modulos inicializados!");
    Serial.printf("[MAIN] IP: %s\n", wifiMgr.getIP().c_str());
    Serial.printf("[MAIN] SD: %s\n", sdLogger.isReady() ? "OK" : "FALHA");
    Serial.println("[MAIN] Loop cooperativo iniciado\n");
}

void loop() {
    unsigned long now = millis();

    // Leitura PZEMs (1s)
    if (now - lastPZEM >= INTERVAL_PZEM) {
        lastPZEM = now;
        pzemReader.readAll(meterData);
        meterData.isoTime = ntpTime.getISO8601();
    }

    // Update OLED (500ms)
    if (now - lastDisplay >= INTERVAL_DISPLAY) {
        lastDisplay = now;
        displayMgr.update(meterData, wifiMgr.getIP(), alarmMgr.hasActiveAlarm());
    }

    // WebSocket broadcast (1s)
    if (now - lastWebSocket >= INTERVAL_WEBSOCKET) {
        lastWebSocket = now;
        webServer.broadcast(meterData);
    }

    // Log SD Card (10s)
    if (now - lastSDLog >= INTERVAL_SD_LOG) {
        lastSDLog = now;
        sdLogger.log(meterData);
    }

    // Publish MQTT (5s)
    if (now - lastMQTT >= INTERVAL_MQTT) {
        lastMQTT = now;
        mqttClient.publish(meterData);
    }

    // Check alarmes (1s)
    if (now - lastAlarm >= INTERVAL_ALARM) {
        lastAlarm = now;
        alarmMgr.check(meterData);
    }

    // Check WiFi (30s)
    if (now - lastWiFiCheck >= INTERVAL_WIFI) {
        lastWiFiCheck = now;
        wifiMgr.check();
    }

    // Sync NTP (1h)
    if (now - lastNTPSync >= INTERVAL_NTP) {
        lastNTPSync = now;
        ntpTime.sync();
    }

    // MQTT loop (non-blocking)
    mqttClient.loop();

    // OTA loop (ArduinoOTA)
    otaMgr.loop();
}

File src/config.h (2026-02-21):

#pragma once

#include <Arduino.h>

// --- Pinos PZEM (Serial2) ---
#define PZEM_RX_PIN    16
#define PZEM_TX_PIN    17

// --- Pinos OLED (I2C) ---
#define OLED_SDA       21
#define OLED_SCL       22
#define OLED_WIDTH     128
#define OLED_HEIGHT    64
#define OLED_ADDR      0x3C

// --- Pinos SD Card (SPI) ---
#define SD_CS_PIN       5
#define SD_MOSI_PIN    23
#define SD_MISO_PIN    19
#define SD_SCK_PIN     18

// --- Buzzer e LED ---
#define BUZZER_PIN      4
#define LED_PIN         2

// --- Enderecos Modbus PZEM ---
#define PZEM_ADDR_L1   0x01
#define PZEM_ADDR_L2   0x02
#define PZEM_ADDR_L3   0x03

// --- WiFi ---
#define WIFI_SSID       "SEU_SSID"
#define WIFI_PASSWORD   "SUA_SENHA"
#define AP_SSID         "Medidor-Config"
#define AP_PASSWORD     "12345678"
#define WIFI_TIMEOUT_MS 15000

// --- MQTT ---
#define MQTT_SERVER     "192.168.1.100"
#define MQTT_PORT       1883
#define MQTT_USER       ""
#define MQTT_PASSWORD   ""
#define MQTT_CLIENT_ID  "medidor-trifasico"
#define MQTT_TOPIC_BASE "medidor"

// --- NTP ---
#define NTP_SERVER      "pool.ntp.org"
#define NTP_GMT_OFFSET  -10800  // BRT = UTC-3
#define NTP_DST_OFFSET  0

// --- Intervalos (ms) ---
#define INTERVAL_PZEM       1000
#define INTERVAL_DISPLAY     500
#define INTERVAL_WEBSOCKET  1000
#define INTERVAL_SD_LOG    10000
#define INTERVAL_MQTT       5000
#define INTERVAL_ALARM      1000
#define INTERVAL_WIFI      30000
#define INTERVAL_NTP     3600000

// --- Display ---
#define DISPLAY_PAGE_INTERVAL 5000
#define DISPLAY_NUM_PAGES     5

// --- Alarmes ---
#define ALARM_OVERVOLTAGE   253.0f  // +15% de 220V
#define ALARM_UNDERVOLTAGE  197.0f  // -10% de 220V
#define ALARM_DEBOUNCE_ON       3   // leituras consecutivas para ativar
#define ALARM_DEBOUNCE_OFF      5   // leituras consecutivas para desativar

// --- SD Logger ---
#define SD_LOG_DIR      "/logs"

// --- Estruturas de dados ---
struct PhaseData {
    float voltage    = 0;
    float current    = 0;
    float power      = 0;
    float energy     = 0;
    float frequency  = 0;
    float powerFactor = 0;
    bool valid       = false;
};

struct MeterData {
    PhaseData phase[3];
    unsigned long timestamp = 0;
    String isoTime;
};

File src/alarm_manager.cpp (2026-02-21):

#include "alarm_manager.h"

void AlarmManager::begin() {
    pinMode(BUZZER_PIN, OUTPUT);
    pinMode(LED_PIN, OUTPUT);
    digitalWrite(BUZZER_PIN, LOW);
    digitalWrite(LED_PIN, LOW);
    Serial.println("[ALARM] Inicializado");
}

void AlarmManager::check(const MeterData& data) {
    bool anyAlarm = false;

    for (int i = 0; i < 3; i++) {
        if (!data.phase[i].valid) continue;

        float v = data.phase[i].voltage;
        AlarmState& s = _state[i];

        if (v > ALARM_OVERVOLTAGE) {
            s.overCount++;
            s.normalCount = 0;
            s.underCount = 0;

            if (s.overCount >= ALARM_DEBOUNCE_ON && !s.overActive) {
                s.overActive = true;
                Serial.printf("[ALARM] SOBRETENSAO L%d: %.1fV\n", i + 1, v);
                if (_callback) _callback(i, "overvoltage", v);
            }
        } else if (v < ALARM_UNDERVOLTAGE) {
            s.underCount++;
            s.normalCount = 0;
            s.overCount = 0;

            if (s.underCount >= ALARM_DEBOUNCE_ON && !s.underActive) {
                s.underActive = true;
                Serial.printf("[ALARM] SUBTENSAO L%d: %.1fV\n", i + 1, v);
                if (_callback) _callback(i, "undervoltage", v);
            }
        } else {
            s.normalCount++;
            s.overCount = 0;
            s.underCount = 0;

            if (s.normalCount >= ALARM_DEBOUNCE_OFF) {
                if (s.overActive || s.underActive) {
                    Serial.printf("[ALARM] Clear L%d: %.1fV\n", i + 1, v);
                    if (_callback) _callback(i, "clear", v);
                }
                s.overActive = false;
                s.underActive = false;
            }
        }

        if (s.overActive || s.underActive) {
            anyAlarm = true;
        }
    }

    if (anyAlarm) {
        activateBuzzer();
        digitalWrite(LED_PIN, HIGH);
    } else {
        deactivateBuzzer();
        digitalWrite(LED_PIN, LOW);
    }
}

bool AlarmManager::hasActiveAlarm() const {
    for (int i = 0; i < 3; i++) {
        if (_state[i].overActive || _state[i].underActive) return true;
    }
    return false;
}

String AlarmManager::getAlarmMessage() const {
    String msg;
    for (int i = 0; i < 3; i++) {
        if (_state[i].overActive) {
            if (msg.length() > 0) msg += " | ";
            msg += "L" + String(i + 1) + ":SOBRE";
        }
        if (_state[i].underActive) {
            if (msg.length() > 0) msg += " | ";
            msg += "L" + String(i + 1) + ":SUB";
        }
    }
    return msg;
}

void AlarmManager::activateBuzzer() {
    unsigned long now = millis();
    // Buzzer intermitente: 200ms on, 800ms off
    if (now - _lastBuzz >= 1000) {
        _lastBuzz = now;
        tone(BUZZER_PIN, 2000, 200);
    }
}

void AlarmManager::deactivateBuzzer() {
    noTone(BUZZER_PIN);
}

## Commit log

2026-02-21 Implementacao completa do medidor trifasico ESP32 + PZEM-004T
    - 3x PZEM-004T v3.0 via Modbus RTU (Serial2)
    - Display OLED SSD1306 com 5 paginas auto-rotativas
    - Dashboard web responsivo com WebSocket e graficos Chart.js
    - Log CSV diario no SD card
    - MQTT com topics individuais e agregado (compativel Home Assistant/Grafana)
    - Alarmes de sub/sobretensao com debounce, buzzer e notificacao web
    - WiFi STA com fallback AP "Medidor-Config"
    - OTA duplo: ArduinoOTA (terminal) + Web OTA (navegador em /update)
    - NTP sincronizado (BRT UTC-3)
    - Utilitario de configuracao de enderecos PZEM
    [partitions.csv]
2026-02-21 Adiciona projeto KiCad PCB e atualiza lista de materiais com precos BR
    - Cria projeto KiCad 7 completo (esquematico + PCB 90x80mm 2 camadas)
    - PCB carrier board para ESP32 DevKit + 3x PZEM-004T + OLED + SD Card
    - Exporta PDF do esquematico e diagrama ASCII de referencia
    - Atualiza LISTA_MATERIAIS.md com precos em R$ (fev/2026)
    - Adiciona links diretos: Usinainfo, Mercado Livre, AliExpress
    - Destaca necessidade de CT split-core (aberto) no PZEM-004T
    [medidor-trifasico.kicad_pcb, medidor-trifasico.kicad_sch]
2026-02-21 Atualiza lista de materiais com links diretos Usinainfo para todos os itens
    Pesquisa completa no site da Usinainfo com codigos, precos PIX e links
    diretos para cada produto. Elimina referencias vagas a "balcao". Adiciona
    opcoes de caixa Patola, tabela detalhada de custo (R$183 Usinainfo +
    PZEM ML/AliExpress), e nota sobre cap 100nF indisponivel.
2026-02-21 Corrige links quebrados da Usinainfo (formato SEO-friendly)
    URLs no formato antigo index.php?route=product/product redirecionavam
    para homepage. Atualiza todos os 9 links para formato SEO novo.
    Corrige precos: ESP32 R$66,36, OLED R$25,46, SD R$7,89, Buzzer R$6,94.
    Subtotal Usinainfo atualizado: R$189,86.
2026-02-21 Adiciona STATUS.md com andamento completo do projeto
    Inclui status do firmware, hardware/PCB, lista de compras com codigos
    e precos confirmados, proximos passos em 4 fases e limitacoes conhecidas.
2026-02-21 Atualiza README com precos BR, estrutura completa e links para docs
    Precos em reais (R$310-390), tabela de materiais com nota sobre CT
    split-core, pinagem com pull-ups e resistores, estrutura atualizada
    com ota_manager e hardware/, secao sobre PCB KiCad, e referencia
    aos arquivos LISTA_MATERIAIS.md e STATUS.md.
2026-02-21 Adiciona landing page GitHub Pages (docs/index.html)
    Site vitrine one-page com: seção motivação (DIY vs Shelly), galeria de 5 dashboards,
    diagrama SVG com zoom, BOM atualizada 2026, toggle PT/EN + dark/light mode.
2026-02-21 Corrige acentos em português e atualiza preços nos .md
    Adiciona acentuação correta (trifásico, tensão, potência, frequência,
    integração, módulo, etc.) nos 3 arquivos markdown. Atualiza preço de
    referência para R$350-430 vs R$900+ Shelly Pro 3EM.
